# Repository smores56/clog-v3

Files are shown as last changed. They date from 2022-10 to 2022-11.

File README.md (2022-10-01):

The Clog V3
===========

The Clog V3 is a 34-key split keyboard. It has the following features:

- Choc V1 switches (solder or hotswap)
- Wireless or wired only with any Pro Micro-compatible controller
- Pinky clusters (top pinky keys on the sides)
- Splay (4° between middle and ring, 8° between ring and pinky)
- SplitKB puck support for tenting

<!-- TODO: update pics -->
One Half of the Clog V2

## How to Order

The [gerber ZIP](./clog-v3.zip) has everything you'll need to get this printed.
You can order from [JLC](https://jlcpcb.com) by just uploading that ZIP archive and keeping
the default options. I'd suggest removing the order number, otherwise they'll put
one on the board somewhere randomly.

## Building

### Parts Needed

Part Name            | Quantity        | Notes                                    | Link
--------------------:|:---------------:|:----------------------------------------:|:----
PCB                  | 2 (halves)      |                                          | Look up hurr hurr
Choc V1 Switches     | 34              |                                          | <https://mkultra.click/choc-switches>
Choc Keycaps         | 34              |                                          | <https://mkultra.click/mbk-factory-colors>
SMD Diodes           | 34              |                                          | <https://www.aliexpress.com/item/3256802562651339.html>
Power Switches       | 2               | Technically optional                     | <https://www.digikey.com/en/products/detail/nidec-copal-electronics/CUS-12TB/1124222>
Xiao BLE             | 2               | Not technically optional                 | <https://www.seeedstudio.com/Seeed-XIAO-BLE-nRF52840-p-5201.html>
Small LiPo Batteries | 2               |                                          | <https://www.aliexpress.com/item/2251832610867849.html>
Inch of Copper Wire  | 1               | Use thin and sheathed                    | Any hardware store
MCU Sockets          | 1 strip to chop | Optional, chop into sections of 7 pins   | <https://www.digikey.com/en/products/detail/mill-max-manufacturing-corp/316-43-164-41-006000/1212147>
MCU Socket Pins      | 28              | Optional, buy extras, these are slippery | <https://www.digikey.com/en/products/detail/mill-max-manufacturing-corp/3320-0-00-15-00-00-03-0/4147392>

### Tips

I'd solder the parts in this order:

- Diodes
- Power switches
- MCU sockets/Headers that came with the Xiao's
- MCU pins if you're [socketing](https://docs.splitkb.com/hc/en-us/articles/360011263059-How-do-I-socket-a-microcontroller-)
- Batteries (To the +ve and -ve terminals)
- The "bodge" wire from the +ve charging pad on the controller to the "Bdg" hole
- Choc switches

## Pictures

The Clog V2

Tented with Pucks and Manfrotto Tripods

The Clog Logo

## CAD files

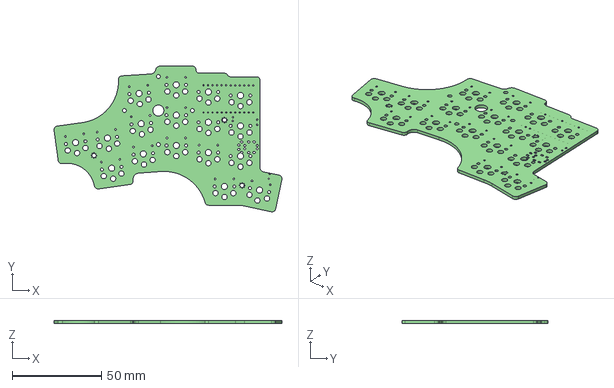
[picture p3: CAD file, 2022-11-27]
case/clog-v3.step
127.8 x 81.8 x 1.60 mm

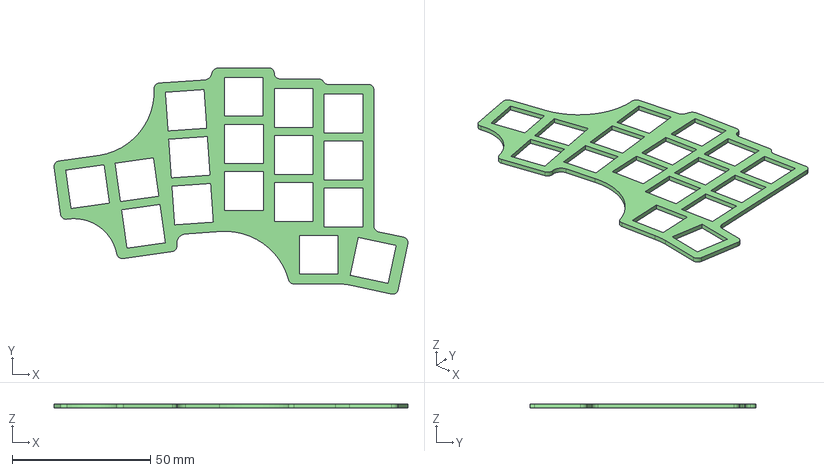
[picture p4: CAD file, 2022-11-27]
case/clog-v3-plate.step
127.8 x 81.8 x 1.60 mm

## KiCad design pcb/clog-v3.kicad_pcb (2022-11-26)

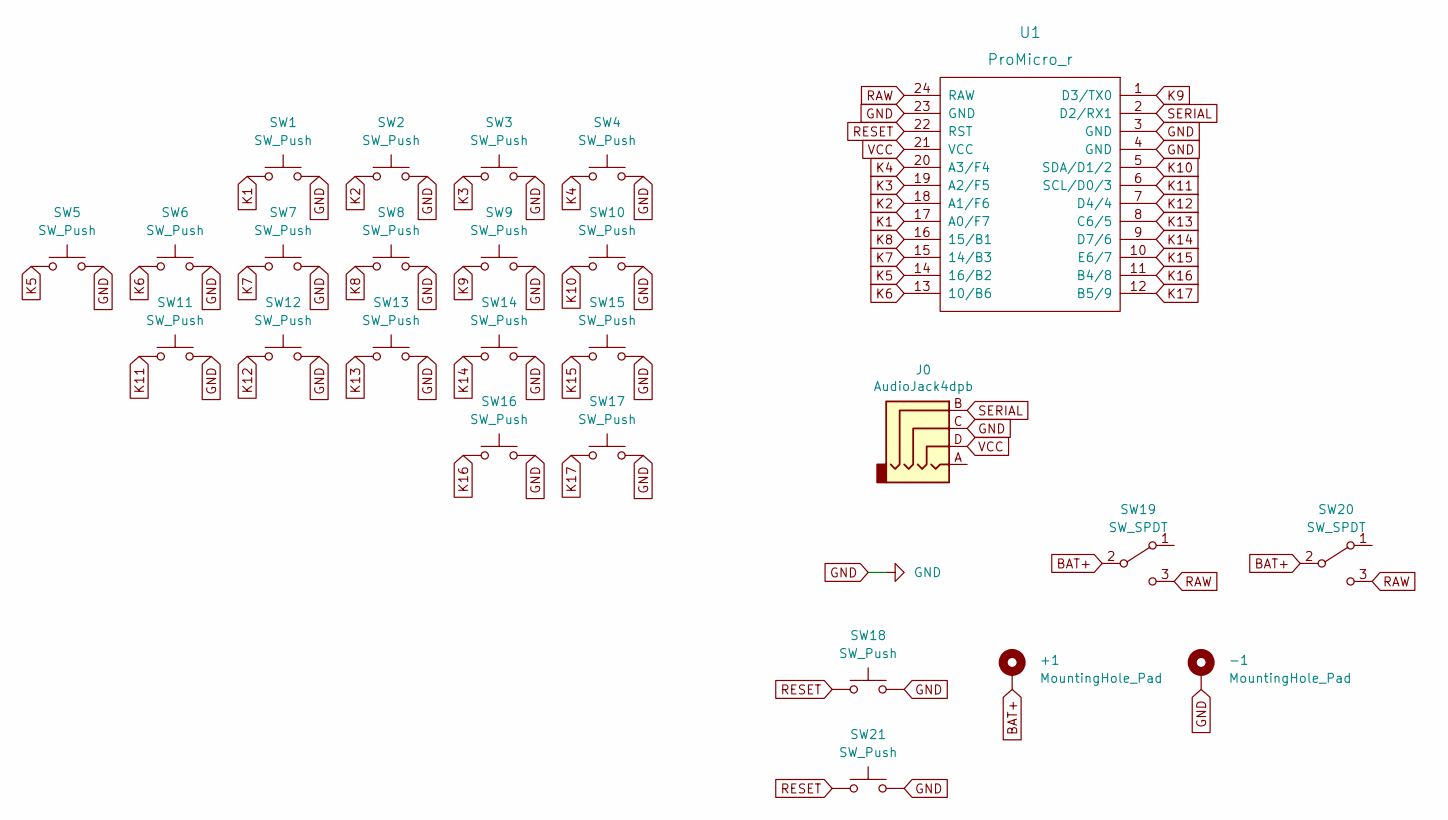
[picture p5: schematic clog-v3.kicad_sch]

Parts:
+1: MountingHole_Pad; single-pin
-1: MountingHole_Pad; single-pin
J0: AudioJack4dpb; trrs
SW1, SW2, SW3, SW4, SW5, SW6, SW7, SW8, SW9, SW10, SW11, SW12, SW13, SW14, SW15, SW16, SW17: SW_Push; choc-switch-socket-only
SW18, SW21: SW_Push; reset-switch-angled-4pin
SW19, SW20: SW_SPDT; power-switch
U1: ProMicro_r; pro-micro

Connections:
BAT+: +1.1, SW19.2 (B), SW20.2 (B)
GND: -1.1, J0.C, SW1.2, SW2.2, SW3.2, SW4.2, SW5.2, SW6.2, SW7.2, SW8.2, SW9.2, SW10.2, SW11.2, SW12.2, SW13.2, SW14.2, SW15.2, SW16.2, SW17.2, SW18.2, SW21.2, U1.3 (GND), U1.4 (GND), U1.23 (GND)
K1: SW1.1, U1.17 (A0/F7)
K2: SW2.1, U1.18 (A1/F6)
K3: SW3.1, U1.19 (A2/F5)
K4: SW4.1, U1.20 (A3/F4)
K5: SW5.1, U1.14 (16/B2)
K6: SW6.1, U1.13 (10/B6)
K7: SW7.1, U1.15 (14/B3)
K8: SW8.1, U1.16 (15/B1)
K9: SW9.1, U1.1 (D3/TX0)
K10: SW10.1, U1.5 (SDA/D1/2)
K11: SW11.1, U1.6 (SCL/D0/3)
K12: SW12.1, U1.7 (D4/4)
K13: SW13.1, U1.8 (C6/5)
K14: SW14.1, U1.9 (D7/6)
K15: SW15.1, U1.10 (E6/7)
K16: SW16.1, U1.11 (B4/8)
K17: SW17.1, U1.12 (B5/9)
RAW: SW19.3 (C), SW20.3 (C), U1.24 (RAW)
RESET: SW18.1, SW21.1, U1.22 (RST)
SERIAL: J0.B, U1.2 (D2/RX1)
VCC: J0.D, U1.21 (VCC)

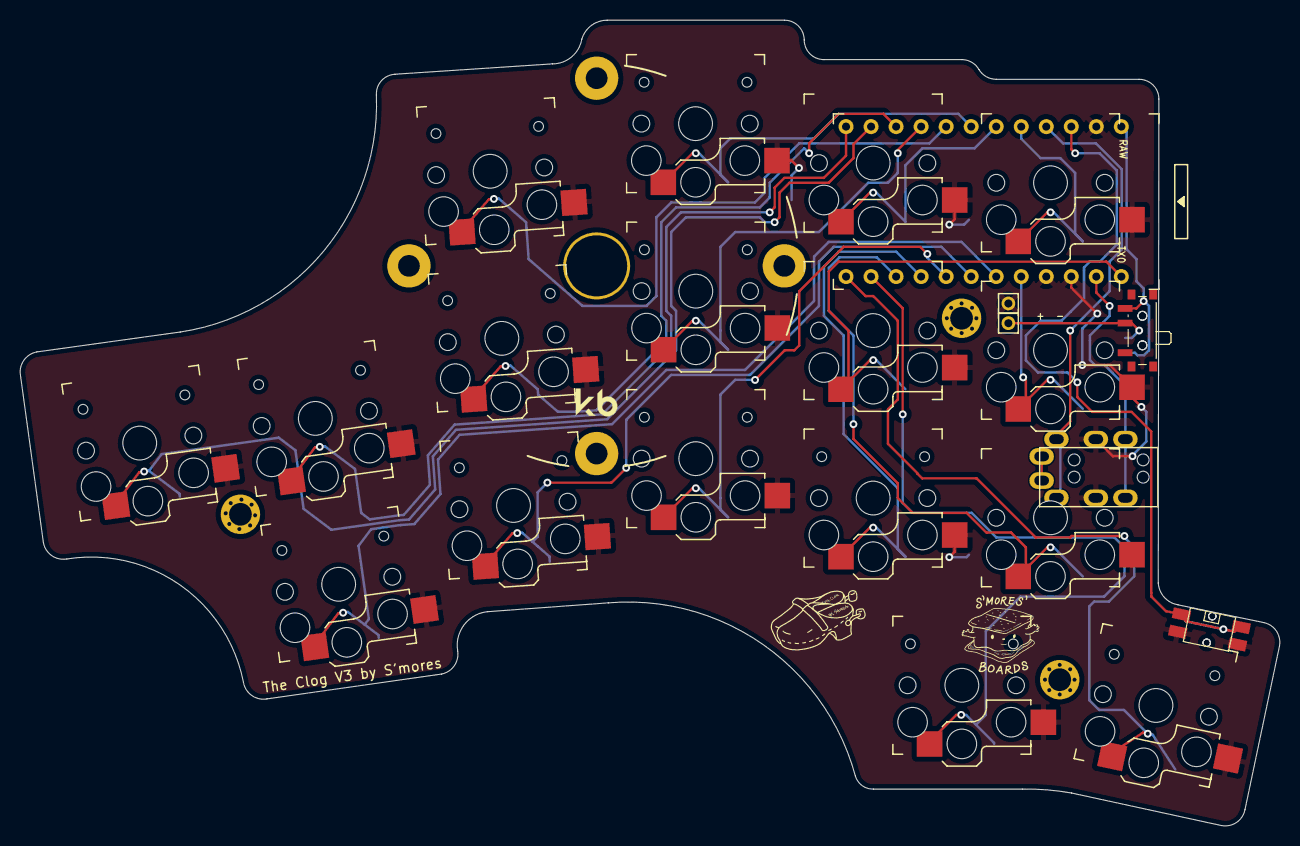
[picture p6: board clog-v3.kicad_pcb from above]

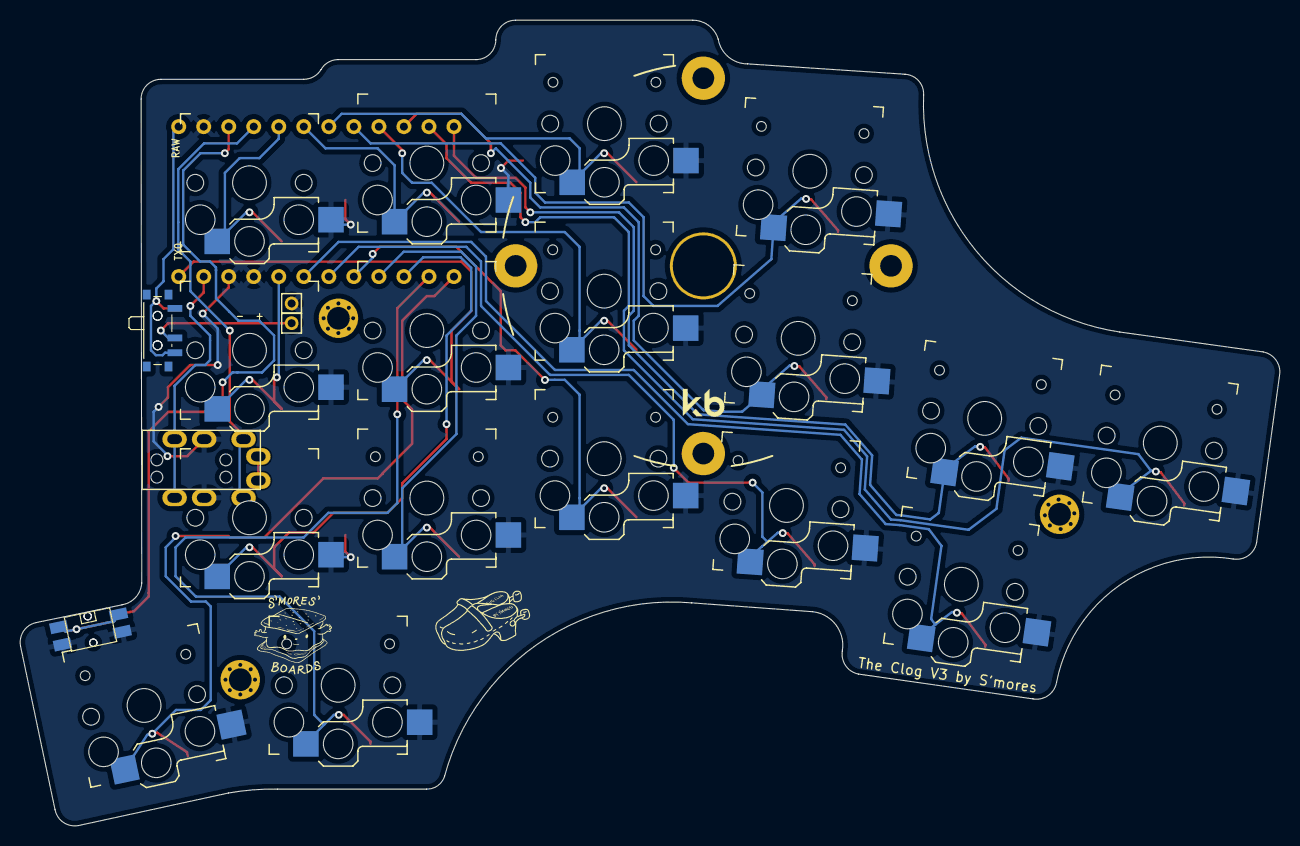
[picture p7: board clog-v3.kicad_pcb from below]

Board: 2 copper layers, 127.8 x 81.8 mm, 28 parts (2 on the bottom side), 23 nets.

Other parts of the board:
Ref**: Val**; m2-hole
Ref**#2, Ref**#3: Val**; m2-hole

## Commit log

2022-11-25 Update Reset Switch, Remove Holes From Plate
    [clog-v3-plate.kicad_pcb, clog-v3.kicad_pcb, clog-v3.kicad_sch]
2022-11-26 Move Pinky Further Up, Rotate Thumbs Out
    [clog-v3-plate.kicad_pcb, clog-v3.kicad_pcb]
2022-11-27 Initial Case Work
    [clog-v3-plate.step, clog-v3.step]
